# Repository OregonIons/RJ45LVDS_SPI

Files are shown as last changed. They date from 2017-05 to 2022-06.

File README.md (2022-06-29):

# RJ45LVDS_SPI

Converts from 4x LVDS over ethernet cable (RJ45) to 4x single-ended digital on a 0.1" header.  
Small footprint board designed to be panel mounted inside a project case.  
Ideal for connecting remote SPI devices to the [Sinara hardware](https://github.com/m-labs/sinara) being designed for [ARTIQ](https://github.com/m-labs/artiq) (specifically the [RJ45_LVDS Kasli module](https://github.com/m-labs/sinara/wiki/EEM_RJ45_LVDS)).  
Voltage translation allows connection to 1.8, 2.5, 3.3, or 5V voltage node logic.

Power
=====

Board requires 3.3V (max current draw is ~200mA). Two options:

1. Apply regulated 3.3V power to the 3.3V pin on either header.  
or
2. Apply unregulated power to UNREG pin and enable the regulator by soldering REG_EN jumper.

- The default regulator is a MIC39100-3.3WS which requires an UNREG input voltage between 3.7 and 16V.  [Datasheet](http://ww1.microchip.com/downloads/en/DeviceDoc/mic39100.pdf)
- When applying unregulated power, the 3.3V pins on the two headers become outputs that can be used to power other things, such as an SPI device. The MIC39100-3.3WS is capable of providing 1A (minus the current required by the board). 
- Adding the optional resistor R5 makes the green LED on the RJ45 jack act as a power indicator.

Channel directions
==================

- Each channel can be independently configured as an input or an output.  
- The channel directions are set via the solder jumpers on the back of the board.  You must set all four directions before powering the board.  
- Each channel has two jumpers which must both be set the same way.

LVDS interface
==============

- Uses Texas Instruments SN65MLVD206 Line Driver and Receiver [Datasheet](http://www.ti.com/lit/ds/symlink/sn65mlvd206.pdf)
- Signalling rates up to 200 Mbps
- Driver has 1.5ns of propagation delay
- Receiver has 4ns of propagation delay

Single-ended digital interface
==============================

- Uses Texas Instruments SN74LVC1T45DBVR Bus Transceiver With Configurable Voltage Translation [Datasheet](http://http://www.ti.com/lit/ds/symlink/sn74lvc1t45.pdf)
- The voltage level of interface must be configured using one of the two V_LOGIC solder jumpers:
1. 3.3V - uses the board’s 3.3V rail
2. EXT - uses voltage supplied at V_LOGIC pin.  Must be in range 1.65-5.5V.
- EXT can be supplied at 'EXT V_LOGIC' pin or the 'UNREG to EXT V_LOGIC' jumper can be used to connect EXT to UNREG.  This would typically be done when powering the board from a regulated +5V supply.
- Propagation delays and data rates depend on V_LOGIC voltage level.  At 3.3V though they are ~4ns and 210Mbps.

RJ45 Connector
==============

Amphenol MRJ-5381-01. See [Datasheet](https://www.amphenolcanada.com/ProductSearch/drawings/AC/MRJ53xxx1.pdf) for panel cutout drawing.

Inverter
========

An optional inverter circuit is provided.  The inverter is an SC70-5 package and is supplied from V_LOGIC.  SN74LVC1GU04 [Datasheet](http://www.ti.com/lit/ds/symlink/sn74lvc1gu04.pdf) is the recommended part as it will work for all supported V_LOGIC voltages (1.8-5V).  Both input and output are wired to a 2-pin 0.1" header  The main envisaged use case is to produce an inverted CS line so that two SPI devices can be driven by the same board.

Release Notes
=============

v0.1 - Initial board fab run.

v0.2 - Second board fab run. Fixed some routing errors that made v0.1 untestable.  Board tested and working.

v0.3 - Changed the RJ45 connector to a right-angled panel-mount version.  Fixed a few silkscreen mistakes.

v0.4 - Fixed a slight error on RJ45 footprint.  Added 3.3V to logic header.  Used nicer solder jumpers.  Added third mounting hole.  Made room so power header could mount on top of board.  Added inverter circuit.

Things to fix in v1.0
=====================

- Inverter input and output labeled wrong on silkscreen.
- Make production files for boardhouse

Licence
=======

Zero-Clause BSD

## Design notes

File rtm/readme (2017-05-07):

tsilk - top silkscreen
tstop - top soldermask
tmetal - top metal
bmetal - bottom metal
bstop - bottom soldermask
bsilk - bottom silkscreen

dim - dimensions

drill - drill file

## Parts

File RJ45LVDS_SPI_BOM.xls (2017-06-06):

Item # | Qty | Ref Des | Manufacturer | Mfg Part # | Dist. Part # | Description | Package
1 | 14 | C1, C2, C3, C4, C5, C6, C7, C8, C11, C12, C13, C14, C15, C17 |  |  |  | .1u | C0603
2 | 3 | C9, C10, C16 | AVX Corporation | TPSB106K020R0500 | 478-9048-1-ND | CAP TANT ,10uF 20V, ESR=500mOhm | SMC_B (1411)
3 | 1 | J1 | Amphenol Commercial Products | MRJ-5381-01 | MRJ-5381-01-ND | CONN MOD JACK 8P8C R/A UNSHLD | MRJ
4 | 1 | JP1 | Amphenol FCI | 67997-112HLF | 609-3227-ND | CONN HEADER 12POS .100 STR 30AU | pinhead
5 | 1 | JP2 | Molex, LLC | 22232041 | WM4202-ND | 1X04 pin header | pinhead
6 | 1 | R1, R2, R3, R4 |  |  |  | 100R | R0603
7 | 1 | R5 |  |  |  | 750R | R0603
8 | 4 | U1, U2, U3, U4 | Texas Instruments | SN65MLVD206 | 296-39192-1-ND | IC M-LVDS LINE DVR/RCVR | 8-SOIC
9 | 4 | U5, U6, U7, U8 | Texas Instruments | SN74LVC1T45DBVR | 296-16843-1-ND | IC BUS TRANSCVR TRI-ST | SOT23
10 | 1 | U9 | Microchip Technology | MIC39100-3.3WS | 576-1172-ND | IC REG LDO 3.3V 1A | SOT223
11 | 1 | U10 | Texas Instruments | SN74LVC1GU04DCKR | 296-8488-1-ND | IC SINGLE INVERTER | SC70-5
12 | 1 | JP3 | Amphenol FCI | 68001-102HLF | 609-3506-ND | CONN HEADER 2POS .100 STR 30AU | pinhead

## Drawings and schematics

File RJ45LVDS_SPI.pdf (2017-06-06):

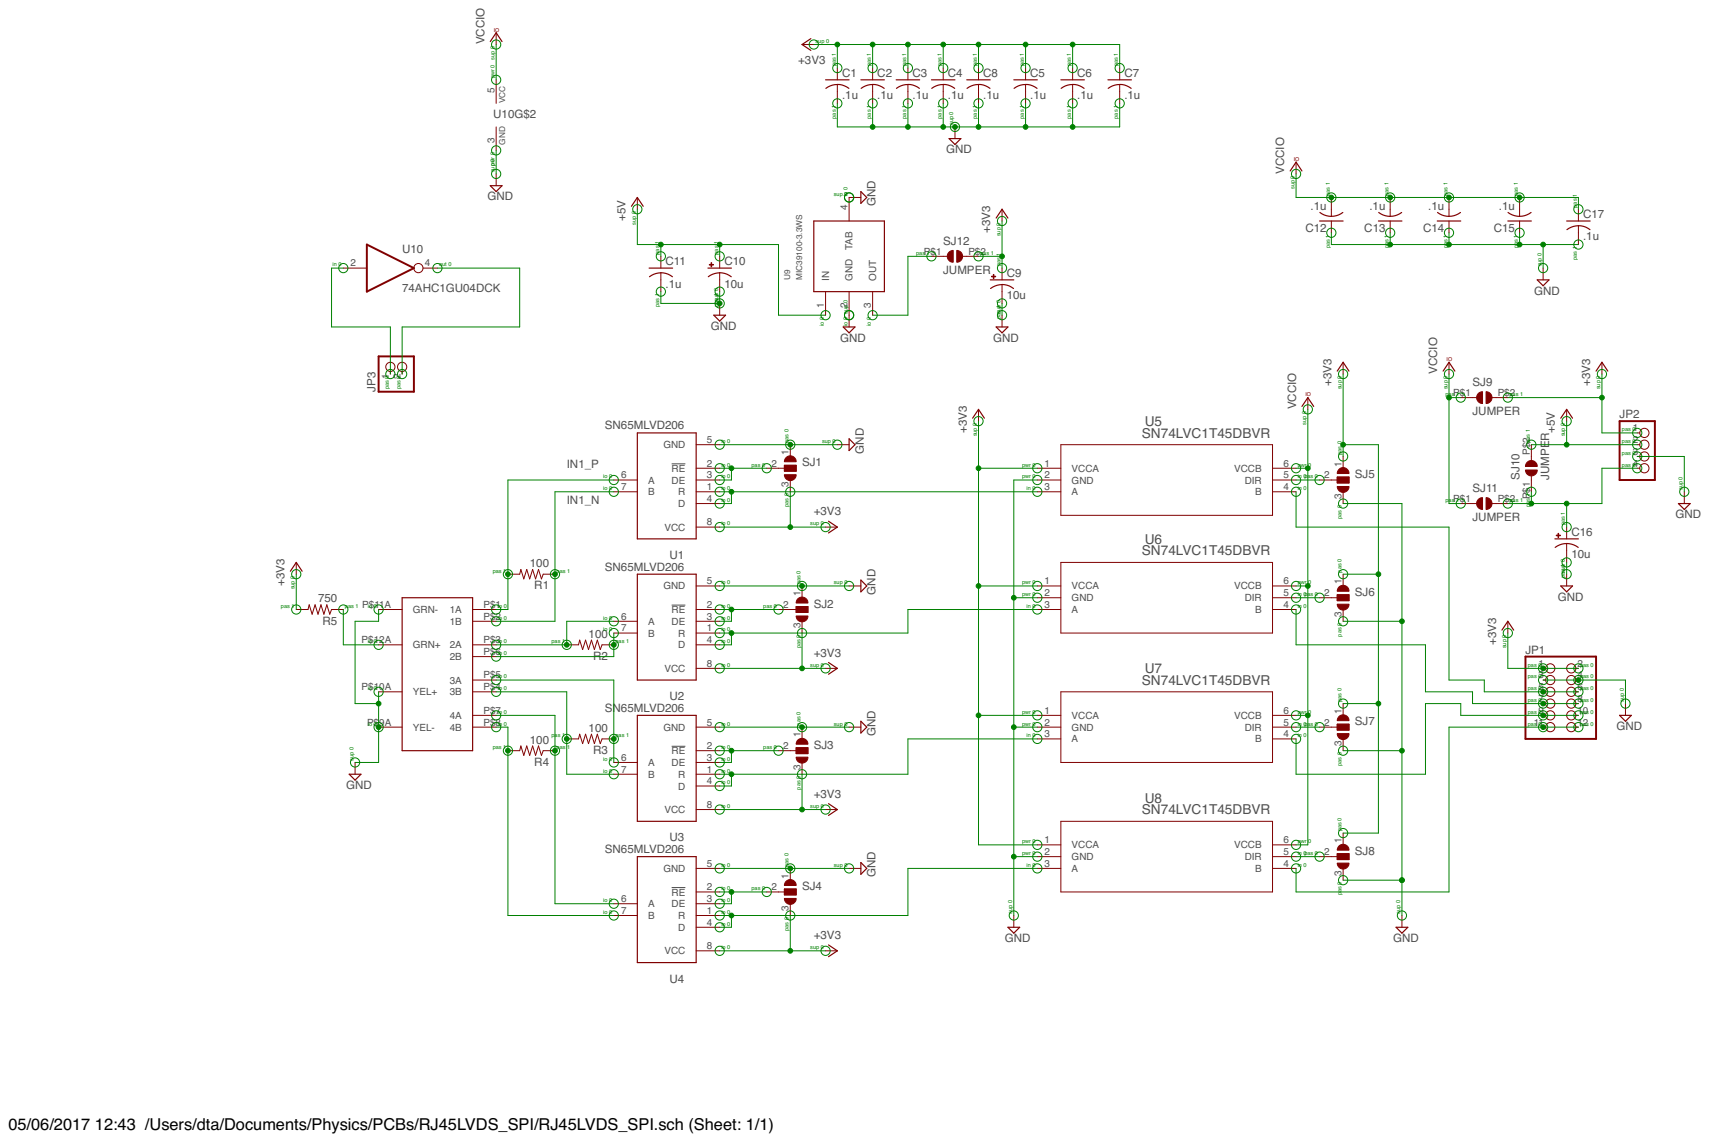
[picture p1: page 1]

pwr 0 pwr 0 sup 0 sup 0

GND GND

05/06/2017 12:43 /Users/dta/Documents/Physics/PCBs/RJ45LVDS_SPI/RJ45LVDS_SPI.sch (Sheet: 1/1)

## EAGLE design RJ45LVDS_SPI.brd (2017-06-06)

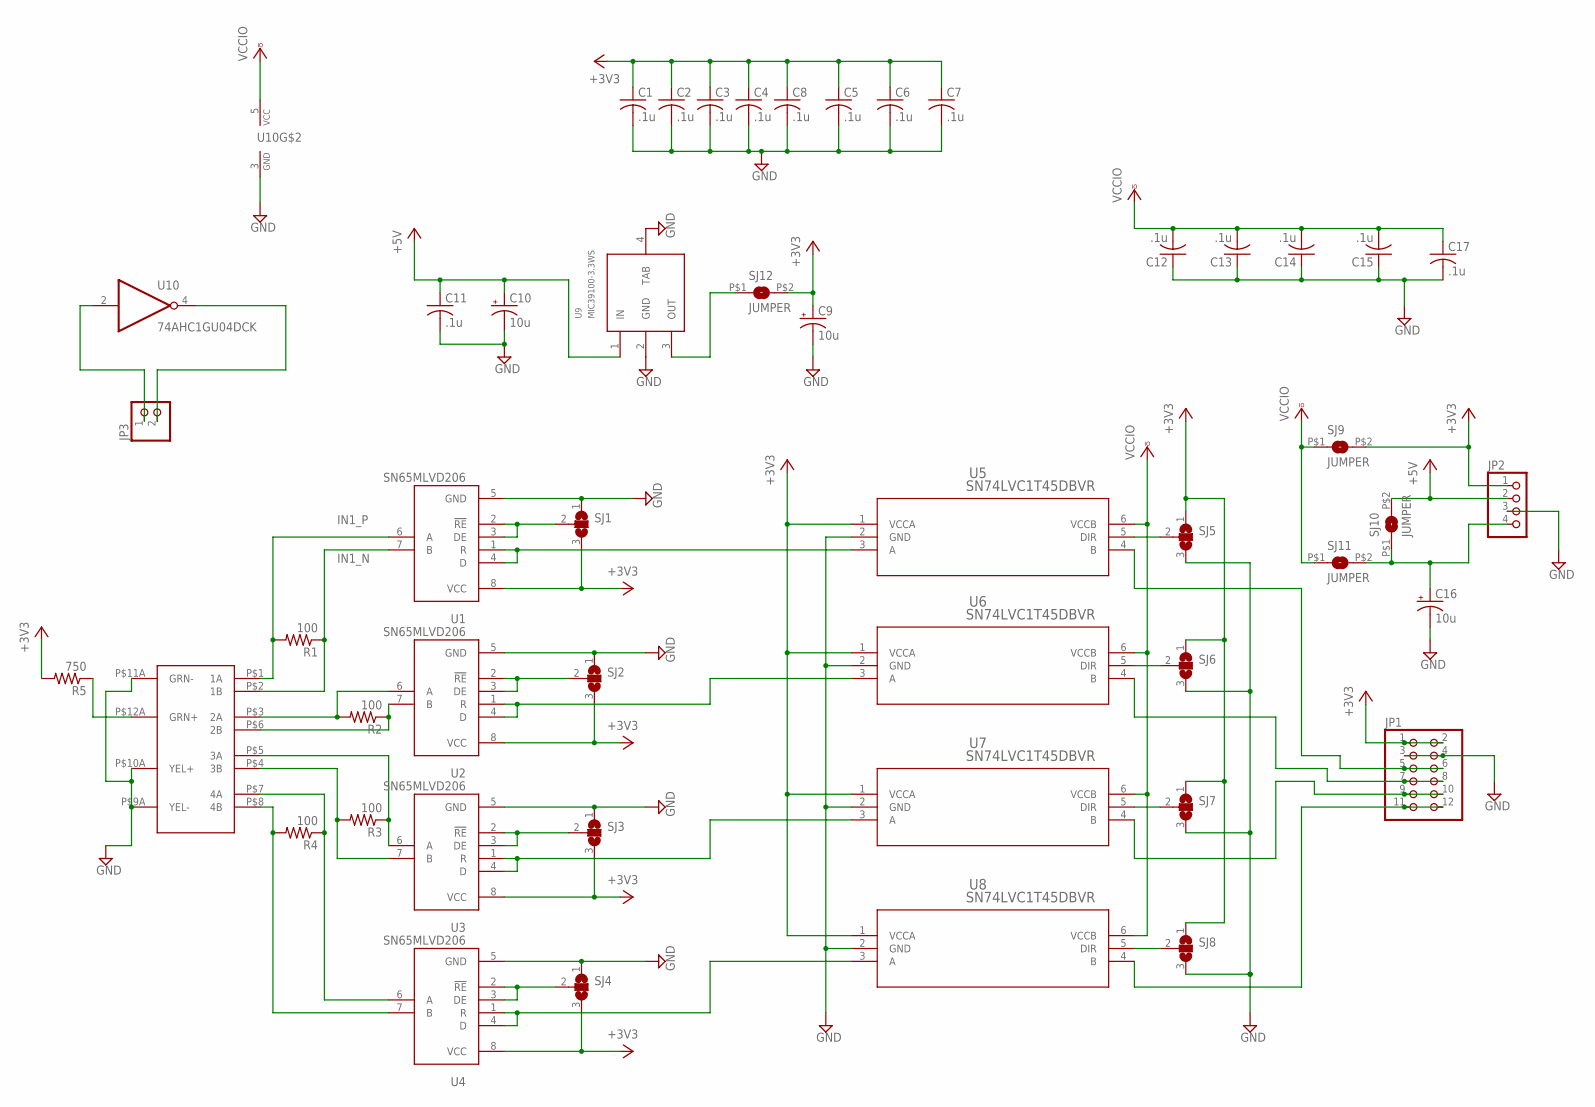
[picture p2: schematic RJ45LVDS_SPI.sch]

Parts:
C1, C2, C3, C4, C5, C6, C7, C8, C11, C12, C13, C14, C15, C17: .1u; C0603
C9, C10, C16: 10u; SMC_B
J1: MRJ; MRJ-MEGAMIX
JP1: PINHD-2X6; 2X06
JP2: PINHD-1X4; 1X04
JP3: PINHD-1X2; 1X02
R1, R2, R3, R4: 100; R0603
R5: 750; R0603
SJ1, SJ2, SJ3, SJ4, SJ5, SJ6, SJ7, SJ8: SJ2W; SJ_2
SJ9, SJ10, SJ11, SJ12: JUMPER; 0603JMP
U1, U2, U3, U4: SN65MLVD206; SOIC08-FAIRCHILD
U5, U6, U7, U8: SN74LVC1T45DBVR; DBV6
U9: MIC39100-3.3WS; SOT223
U10: 74AHC1GU04DCK; SC70-5

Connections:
1_33: U1.1 (R), U1.4 (D), U5.3 (A)
2_33: U2.1 (R), U2.4 (D), U6.3 (A)
3_33: U3.1 (R), U3.4 (D), U7.3 (A)
4_33: U4.1 (R), U4.4 (D), U8.3 (A)
+3V3: C1.1, C2.1, C3.1, C4.1, C5.1, C6.1, C7.1, C8.1, C9.+, JP1.1, JP1.2, JP2.1, R5.2, SJ1.3, SJ2.3, SJ3.3, SJ4.3, SJ5.1, SJ6.1, SJ7.1, SJ8.1, SJ9.P$2 (2), SJ12.P$2 (2), U1.8 (VCC), U2.8 (VCC), U3.8 (VCC), U4.8 (VCC), U5.1 (VCCA), U6.1 (VCCA), U7.1 (VCCA), U8.1 (VCCA)
+5V: C10.+, C11.1, JP2.2, SJ10.P$2 (2), U9.1 (IN)
A: JP3.1, U10.2 (I)
GND: C1.2, C2.2, C3.2, C4.2, C5.2, C6.2, C7.2, C8.2, C9.-, C10.-, C11.2, C12.1, C13.1, C14.1, C15.1, C16.-, C17.2, J1.P$9A (YEL-), J1.P$10A (YEL+), J1.P$11A (GRN-), JP1.3, JP1.4, JP2.3, SJ1.1, SJ2.1, SJ3.1, SJ4.1, SJ5.3, SJ6.3, SJ7.3, SJ8.3, U1.5 (GND), U2.5 (GND), U3.5 (GND), U4.5 (GND), U5.2 (GND), U6.2 (GND), U7.2 (GND), U8.2 (GND), U9.2 (GND), U9.4 (TAB), U10.3 (GND)
IN1_N: J1.P$2 (1B), R1.1, U1.7 (B)
IN1_P: J1.P$1 (1A), R1.2, U1.6 (A)
IN2_N: J1.P$6 (2B), R2.1, U2.7 (B)
IN2_P: J1.P$3 (2A), R2.2, U2.6 (A)
IN3_N: J1.P$4 (3B), R3.2, U3.7 (B)
IN3_P: J1.P$5 (3A), R3.1, U3.6 (A)
IN4_N: J1.P$8 (4B), R4.2, U4.7 (B)
IN4_P: J1.P$7 (4A), R4.1, U4.6 (A)
unnamed: SJ3.2, U3.2 (!RE), U3.3 (DE)
unnamed: SJ2.2, U2.2 (!RE), U2.3 (DE)
unnamed: SJ4.2, U4.2 (!RE), U4.3 (DE)
unnamed: SJ1.2, U1.2 (!RE), U1.3 (DE)
unnamed: SJ8.2, U8.5 (DIR)
unnamed: JP1.11, JP1.12, U8.4 (B)
unnamed: SJ5.2, U5.5 (DIR)
unnamed: SJ7.2, U7.5 (DIR)
unnamed: SJ6.2, U6.5 (DIR)
unnamed: JP1.5, JP1.6, U5.4 (B)
unnamed: JP1.7, JP1.8, U6.4 (B)
unnamed: JP1.9, JP1.10, U7.4 (B)
unnamed: C16.+, JP2.4, SJ10.P$1 (1), SJ11.P$2 (2)
unnamed: SJ12.P$1 (1), U9.3 (OUT)
unnamed: J1.P$12A (GRN+), R5.1
NOT_A: JP3.2, U10.4 (O)
VCCIO: C12.2, C13.2, C14.2, C15.2, C17.1, SJ9.P$1 (1), SJ11.P$1 (1), U5.6 (VCCB), U6.6 (VCCB), U7.6 (VCCB), U8.6 (VCCB), U10.5 (VCC)

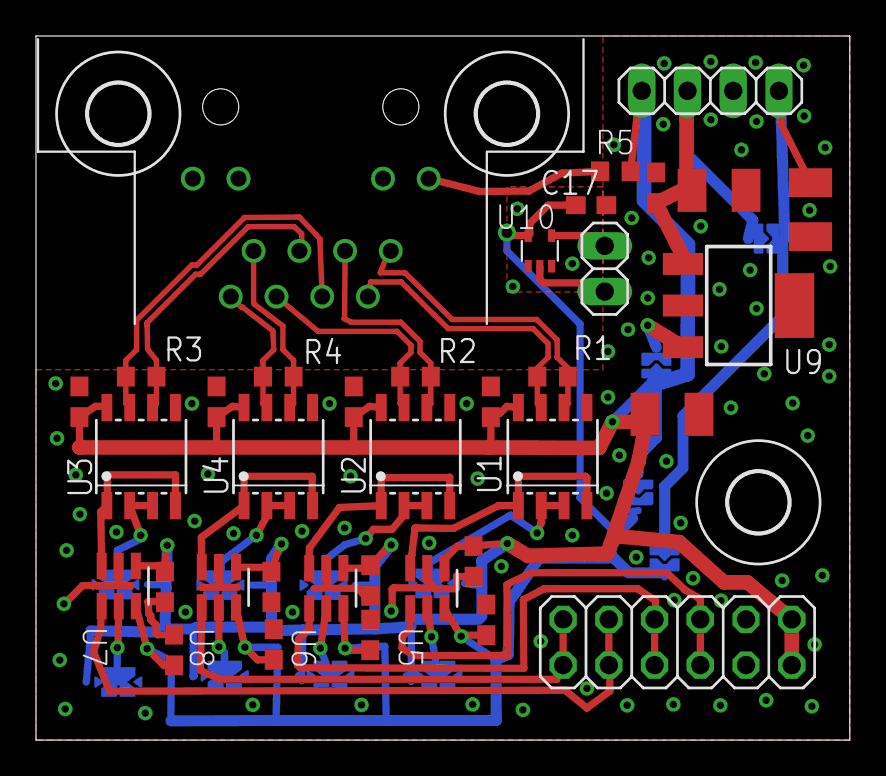
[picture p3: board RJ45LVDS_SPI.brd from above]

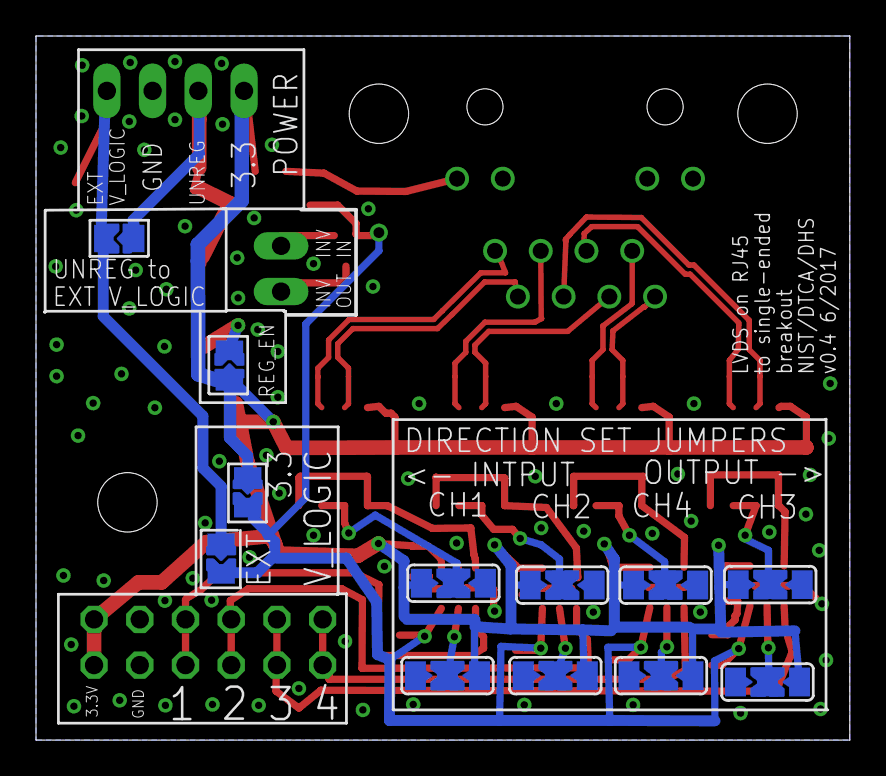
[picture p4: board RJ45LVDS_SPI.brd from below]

Board: 2 copper layers, 45.2 x 39.1 mm, 51 parts (12 on the bottom side), 33 nets.

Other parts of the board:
U$1, U$2, U$3: 3,3

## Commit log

2017-04-19 Added boards
    [RJ45LVDS_SPI.brd, RJ45LVDS_SPI.sch]
2017-04-21 added level translators
    [RJ45LVDS_SPI.brd]
2017-04-21 documentation update
    [RJ45LVDS_SPI.brd, RJ45LVDS_SPI.sch]
2017-04-21 deleted backup files
    [RJ45LVDS_SPI.brd, RJ45LVDS_SPI.sch]
2017-04-22 Bom added
    [RJ45LVDS_SPI.brd, RJ45LVDS_SPI.sch, RJ45LVDS_SPI_BOM.xls]
2017-04-25 Added mount holes
    [RJ45LVDS_SPI.brd, RJ45LVDS_SPI.sch]
2017-04-25 layout tweaks
    [RJ45LVDS_SPI.brd, RJ45LVDS_SPI.sch]
2017-04-27 Tidy up and update pdf
    [RJ45LVDS_SPI.brd, RJ45LVDS_SPI.sch]
2017-04-27 fixed labelling on board
    [RJ45LVDS_SPI.brd]
2017-04-28 Board tweaks and added gerbers
    [RJ45LVDS_SPI.brd, RJ45LVDS_SPI.sch]
2017-05-07 Fixed problems with v1.0 board
    [RJ45LVDS_SPI.brd]
2017-05-18 Changed RJ45 footprint
    [RJ45LVDS_SPI.brd, RJ45LVDS_SPI.sch, RJ45LVDS_SPI_BOM.xls]
2017-05-23 Fixed RJ45 footprint issue
    [RJ45LVDS_SPI.brd, RJ45LVDS_SPI.sch]
2017-05-23 Updated BOM and pdf
    [RJ45LVDS_SPI_BOM.xls]
2017-06-06 v0.4 changes
    [RJ45LVDS_SPI.brd, RJ45LVDS_SPI.sch, RJ45LVDS_SPI_BOM.xls]
